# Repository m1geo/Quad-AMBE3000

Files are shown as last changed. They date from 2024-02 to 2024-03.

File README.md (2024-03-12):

# Quad-AMBE3000
A PCB for four DVSI AMBE-3000R (or AMBE-3003) Vocoders for use with WebSDRs/Audio transcoding.

Using four AMBE-3000R parts was cheaper than using a single AMBE-3003, which was the original plan. 
This is useful for VHF, UHF, SHF WebSDR platforms that decode D-Star, DMR, YSF, NXDN, P25, etc.
A soft-codec approach based on [mbelib](https://github.com/szechyjs/mbelib) can be used, but appeared to give poorer decode audio when tested.

Using four AMBE-3003 parts gives a total of 12 similtaneous transcode streams. the '3003 part requires 1V9 instead of 1V8. You may also benefit from increasing the `S_COM_RATE` to 921,600kbps, by changing `S_COM_RATE0` from low to high. See the devices respective datasheets.

The DVSI AMBE parts can be purchased in low volume from the [DVSI Inc. Hardware Product Pricing](https://www.dvsinc.com/products/price.shtml) page. You will need to create a purchase order to buy from DVSI.

# Assembly

The design schematic include details for [JLCPCB](https://jlcpcb.com/) assembly, who assembled mine. You'll likely have to reflow the DVSI AMBE-3000R part yourself, which I did with a PCB reflow hotplate, but you can do any way you wish.

Each schematic component has a [JLCPCB Parts](https://jlcpcb.com/parts)/[LCSC](https://www.lcsc.com/) part number (Cxxxxxx), which can be exported to the BoM using the extra field "LCSC".

# Schematic

[PDF schematic can be found here](outputs/Quad-AMBE3000_Sch.pdf)

# Images

Front PCB

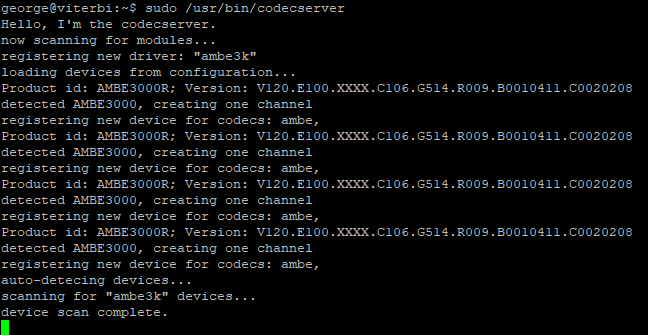
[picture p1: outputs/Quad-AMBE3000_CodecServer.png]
OpenWebRX CodecServer


# 3D Renders

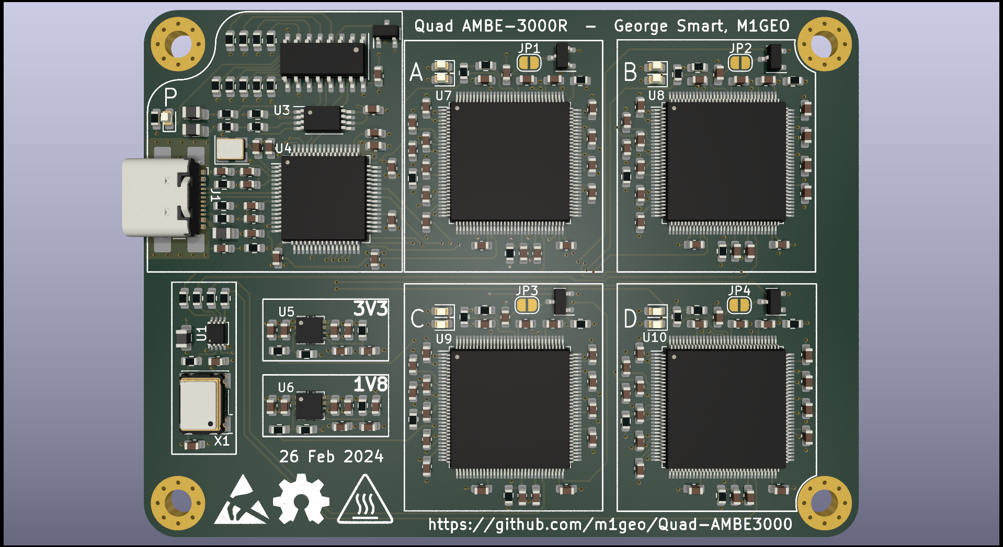
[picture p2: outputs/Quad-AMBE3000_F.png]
Front Render


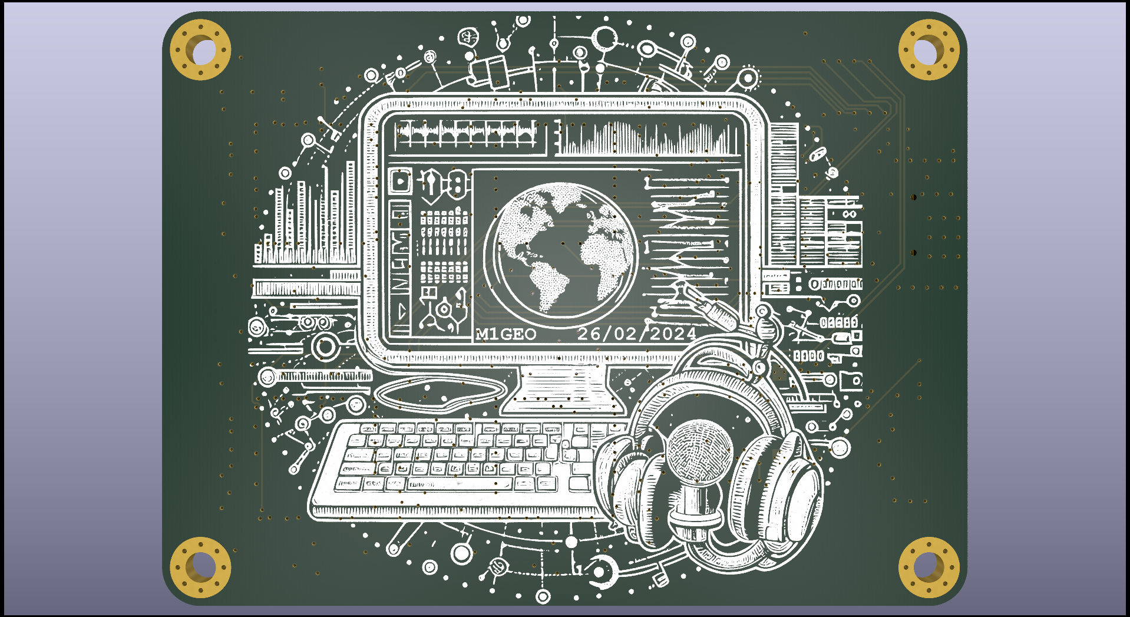
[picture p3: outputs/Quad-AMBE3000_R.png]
Rear Render


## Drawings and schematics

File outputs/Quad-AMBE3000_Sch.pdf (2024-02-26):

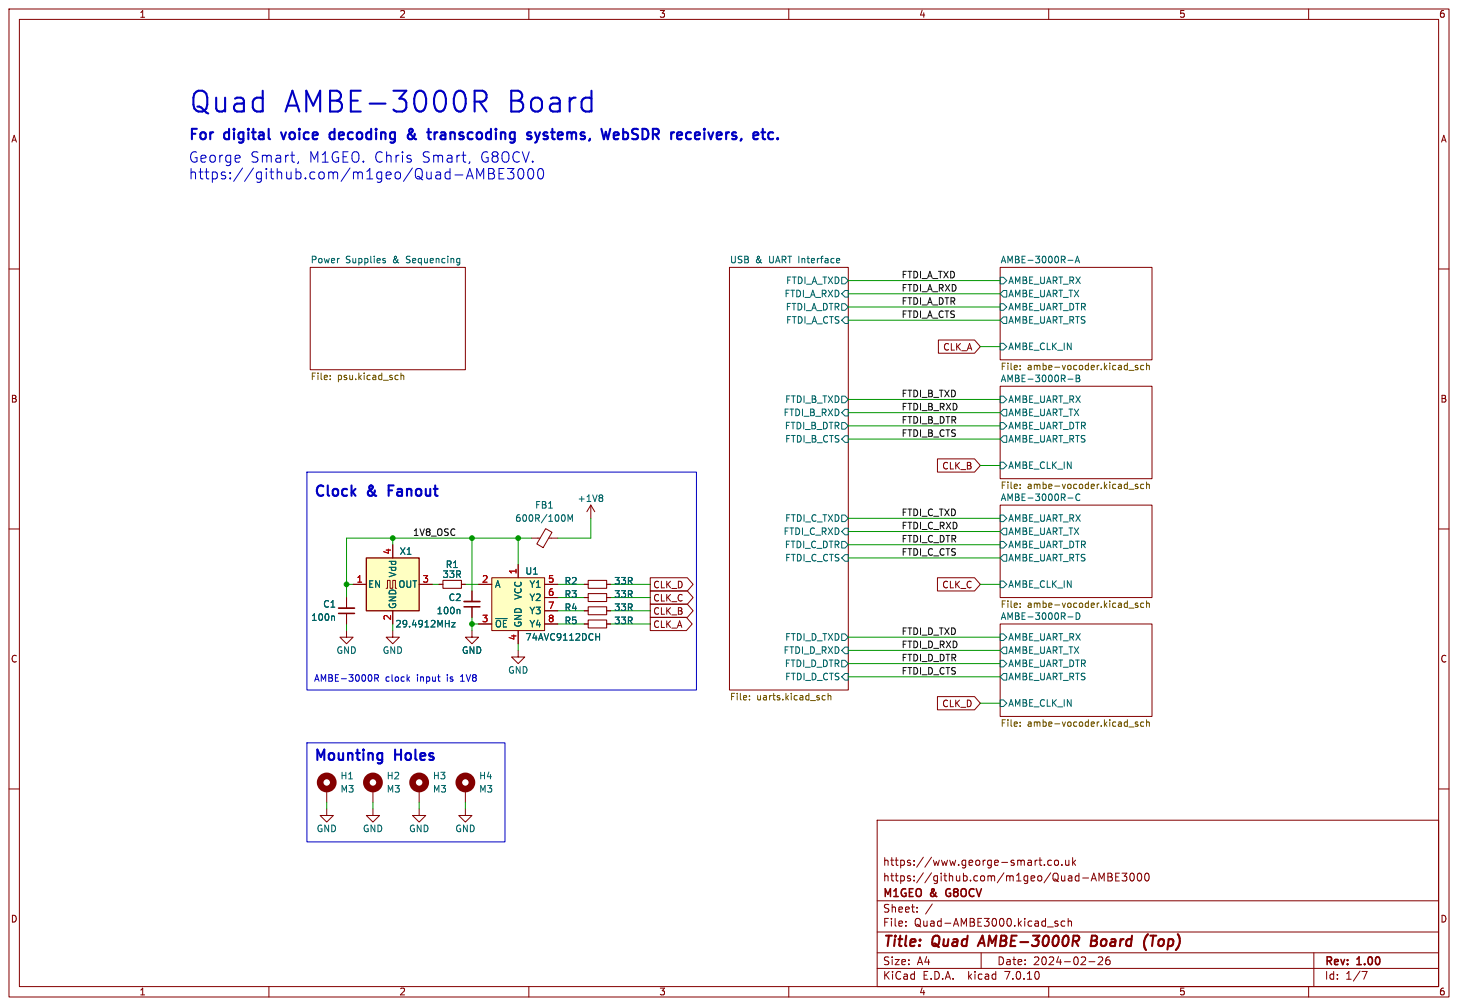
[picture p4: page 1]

For digital voice decoding & transcoding systems, WebSDR receivers, etc.
https://github.com/m1geo/Quad-AMBE3000

https://www.george-smart.co.uk

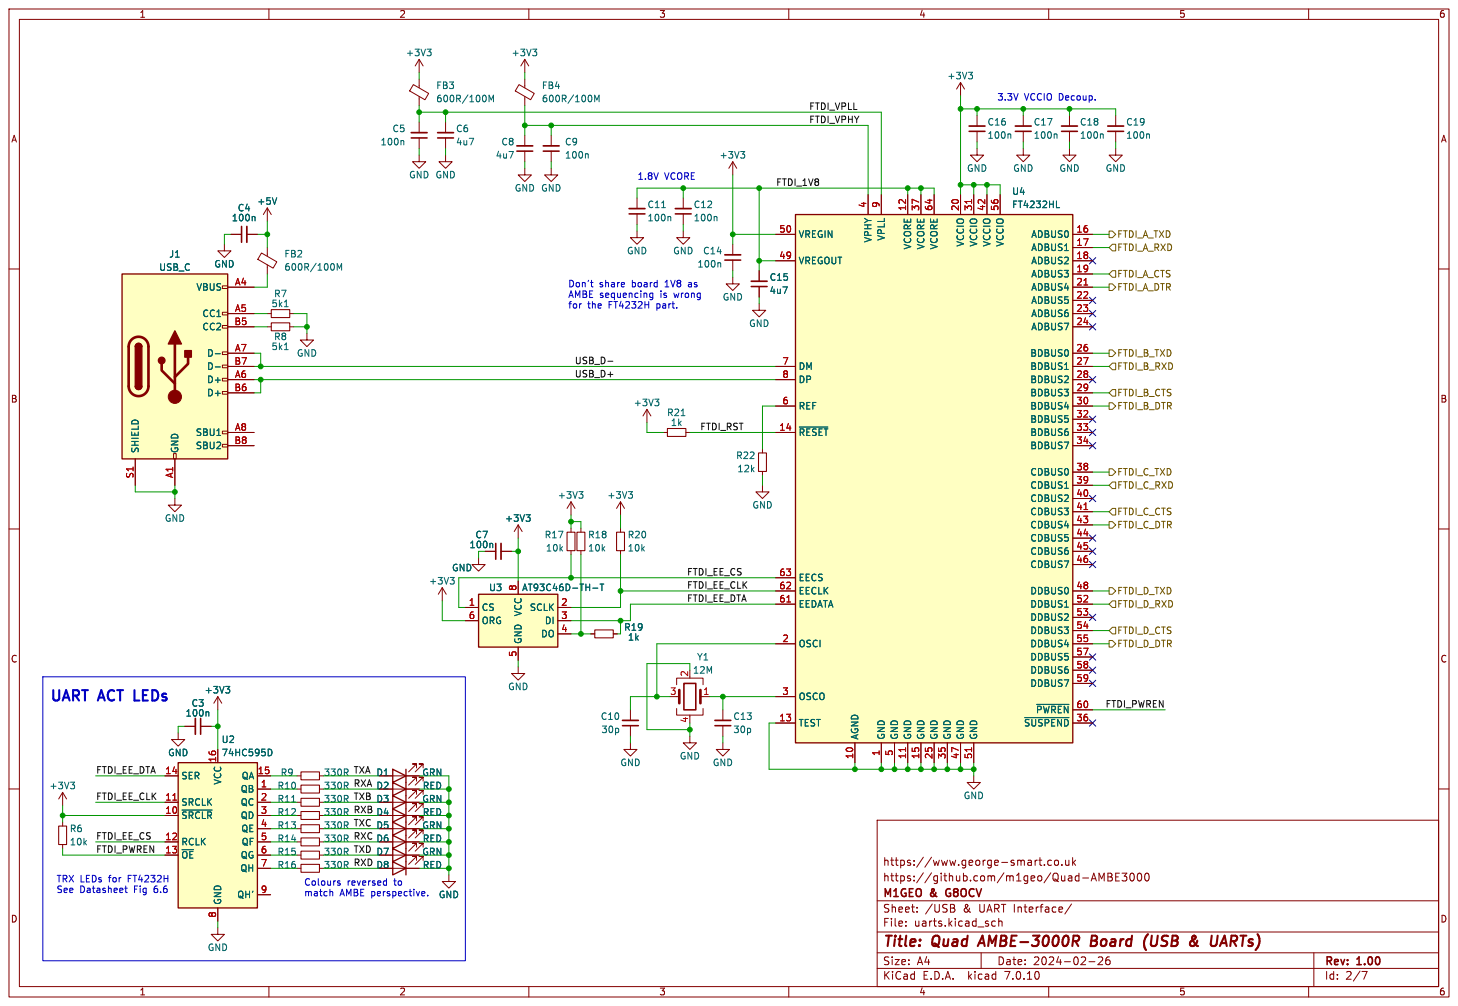
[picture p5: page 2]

1 AGND 10 GND 11 VCORE 12 TEST 13 ~{RESET} 14 GND 15 ADBUS0 16 ADBUS1 17 ADBUS2 18 ADBUS3 19 OSCI 2 VCCIO 20 ADBUS4 21 ADBUS5 22 ADBUS6 23 ADBUS7 24 GND 25 BDBUS0 26 BDBUS1 27 BDBUS2 28 BDBUS3 29 OSCO 3 BDBUS4 30 VCCIO 31 BDBUS5 32 BDBUS6 33 BDBUS7 34 GND 35

4 CDBUS2 40 CDBUS3 41 VCCIO 42 CDBUS4 43 CDBUS5 44 CDBUS6 45 CDBUS7 46 GND 47 DDBUS0 48 VREGOUT 49 GND

5 VREGIN 50 GND 51 DDBUS1 52 DDBUS2 53 DDBUS3 54 DDBUS4 55 VCCIO 56 DDBUS5 57 DDBUS6 58 DDBUS7 59 REF 6 ~{PWREN}60 EEDATA 61 EECLK 62 EECS 63 VCORE 64 DM 7 DP 8 VPLL

for the FT4232H part. TRX LEDs for FT4232H

Colours reversed to match AMBE perspective.

https://www.george-smart.co.uk
https://github.com/m1geo/Quad-AMBE3000

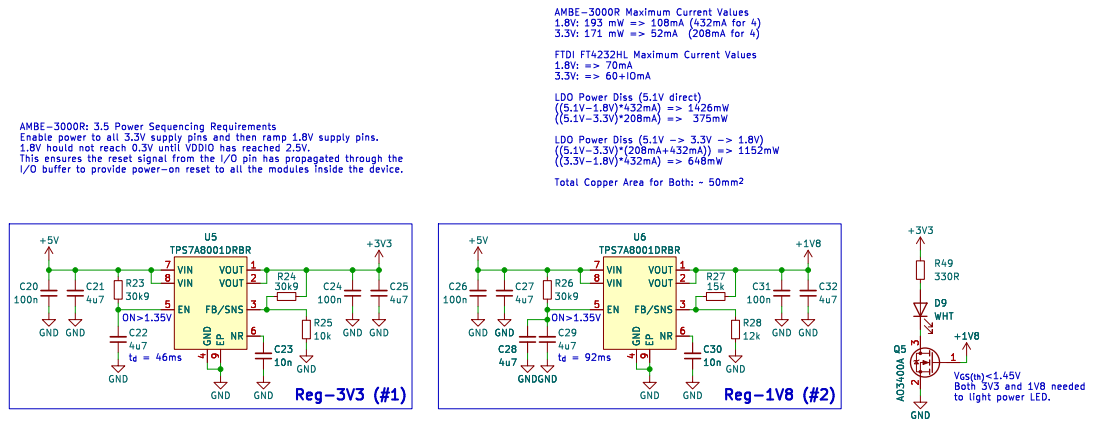
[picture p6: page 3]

LDO Power Diss (5.1V direct)

Total Copper Area for Both: ~ 50mm^{2}

4 EN 5 NR 6 VIN 7 VIN 8 EP

Both 3V3 and 1V8 needed
to light power LED.

https://www.george-smart.co.uk
https://github.com/m1geo/Quad-AMBE3000

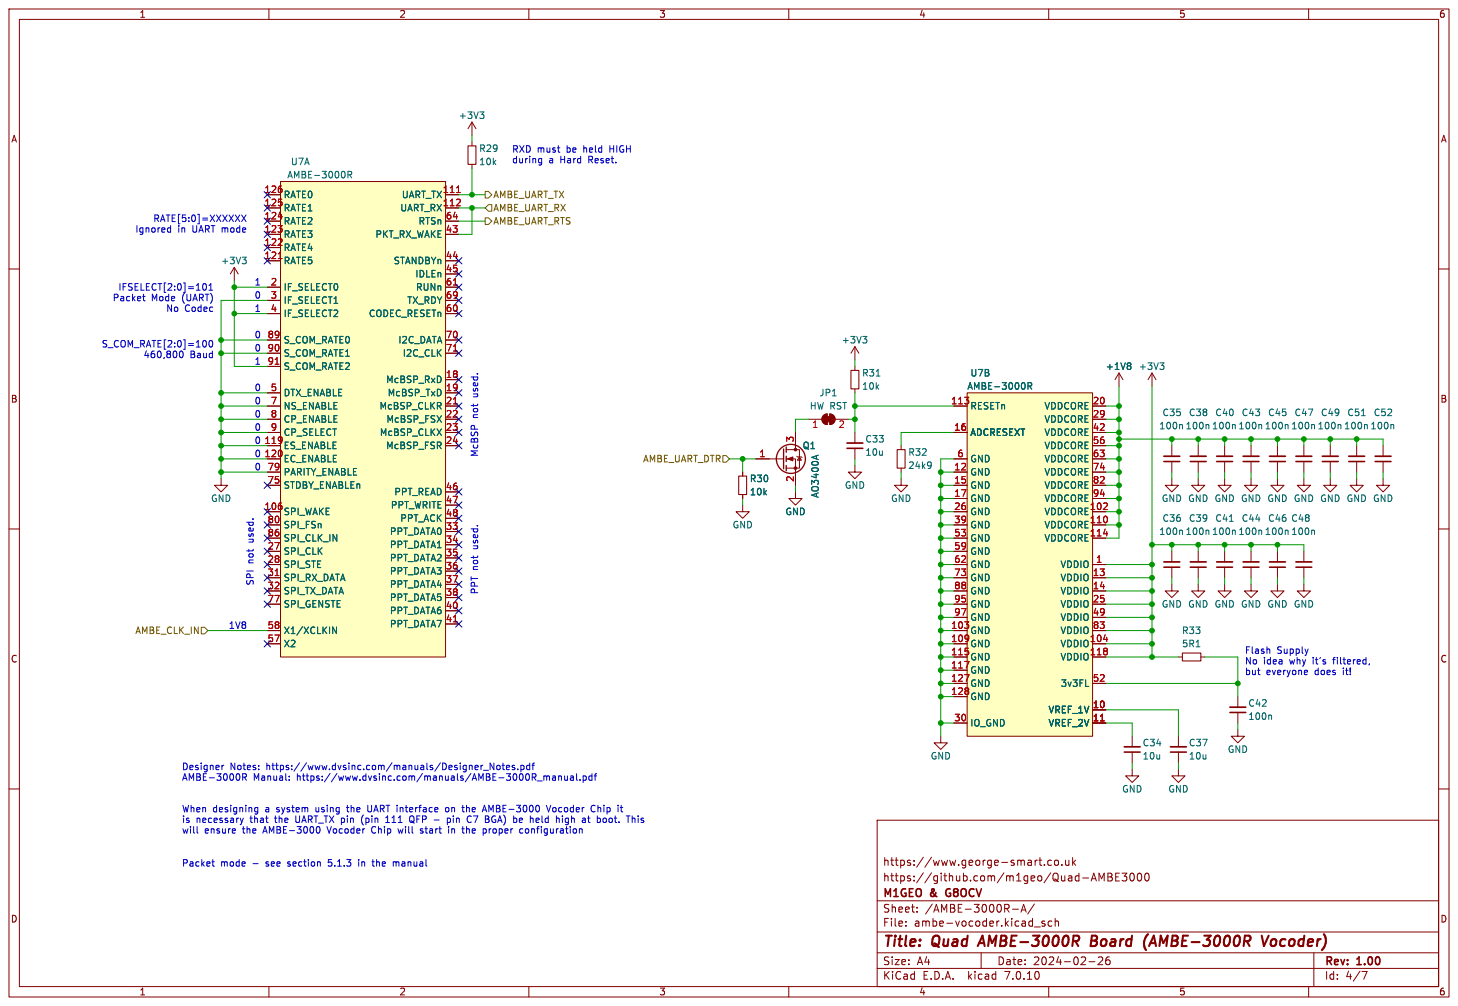
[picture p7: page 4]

0 RATE[5:0]=XXXXXX
Ignored in UART mode

IFSELECT[2:0]=101 Packet Mode (UART) No Codec S_COM_RATE[2:0]=100

Flash Supply No idea why it's filtered, but everyone does it! 0

https://www.george-smart.co.uk
https://github.com/m1geo/Quad-AMBE3000

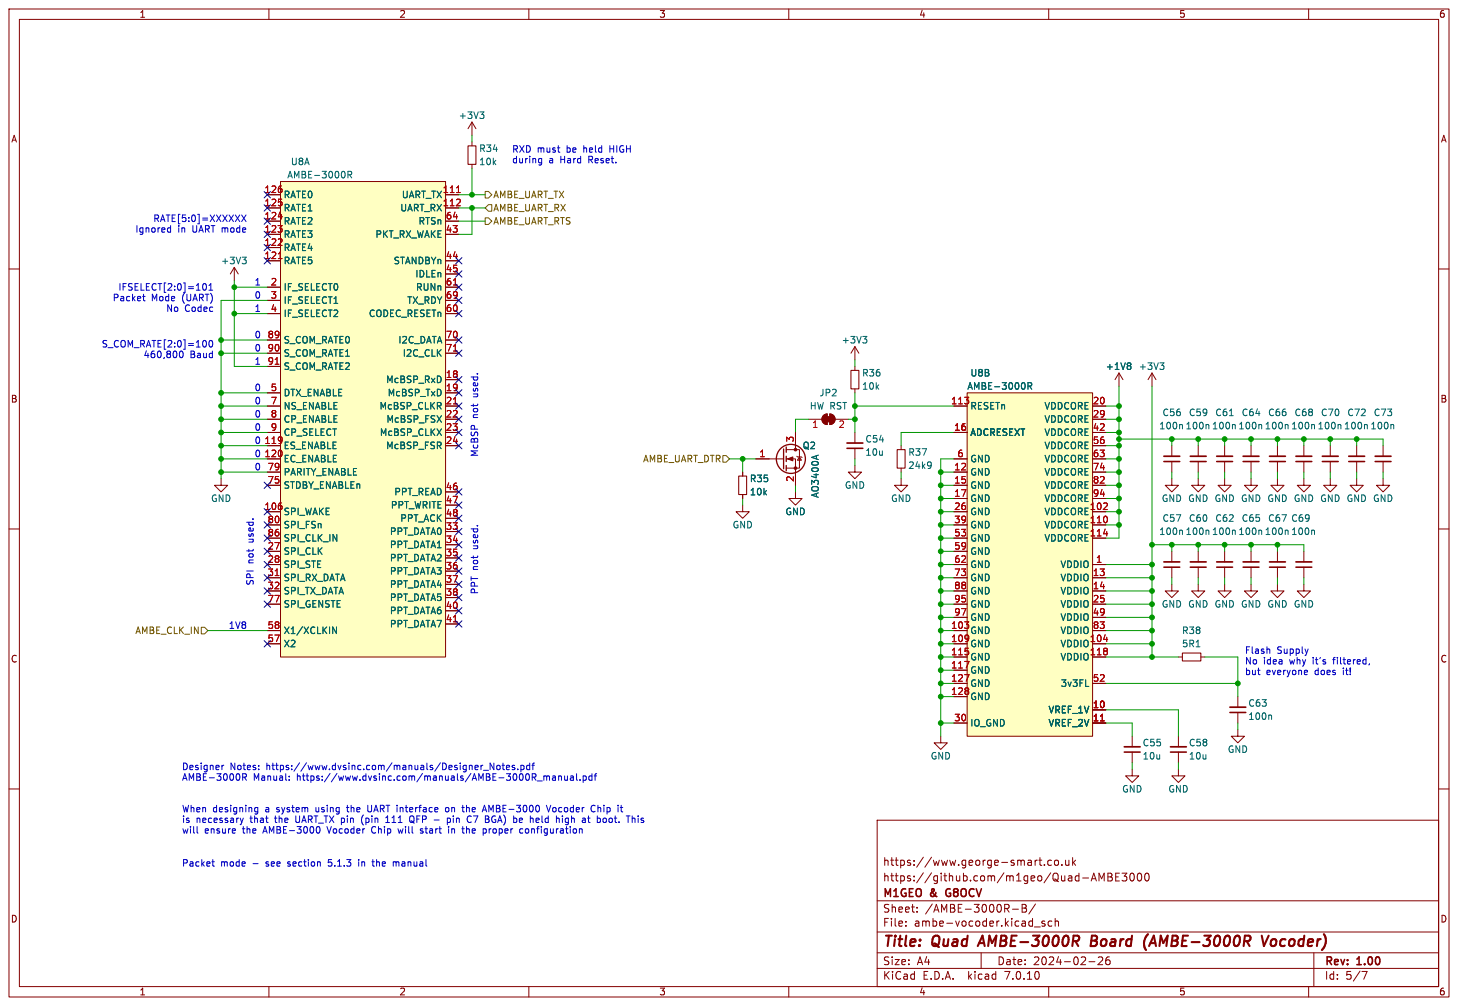
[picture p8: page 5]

0 RATE[5:0]=XXXXXX
Ignored in UART mode

IFSELECT[2:0]=101 Packet Mode (UART) No Codec S_COM_RATE[2:0]=100

Flash Supply No idea why it's filtered, but everyone does it! 0

https://www.george-smart.co.uk
https://github.com/m1geo/Quad-AMBE3000

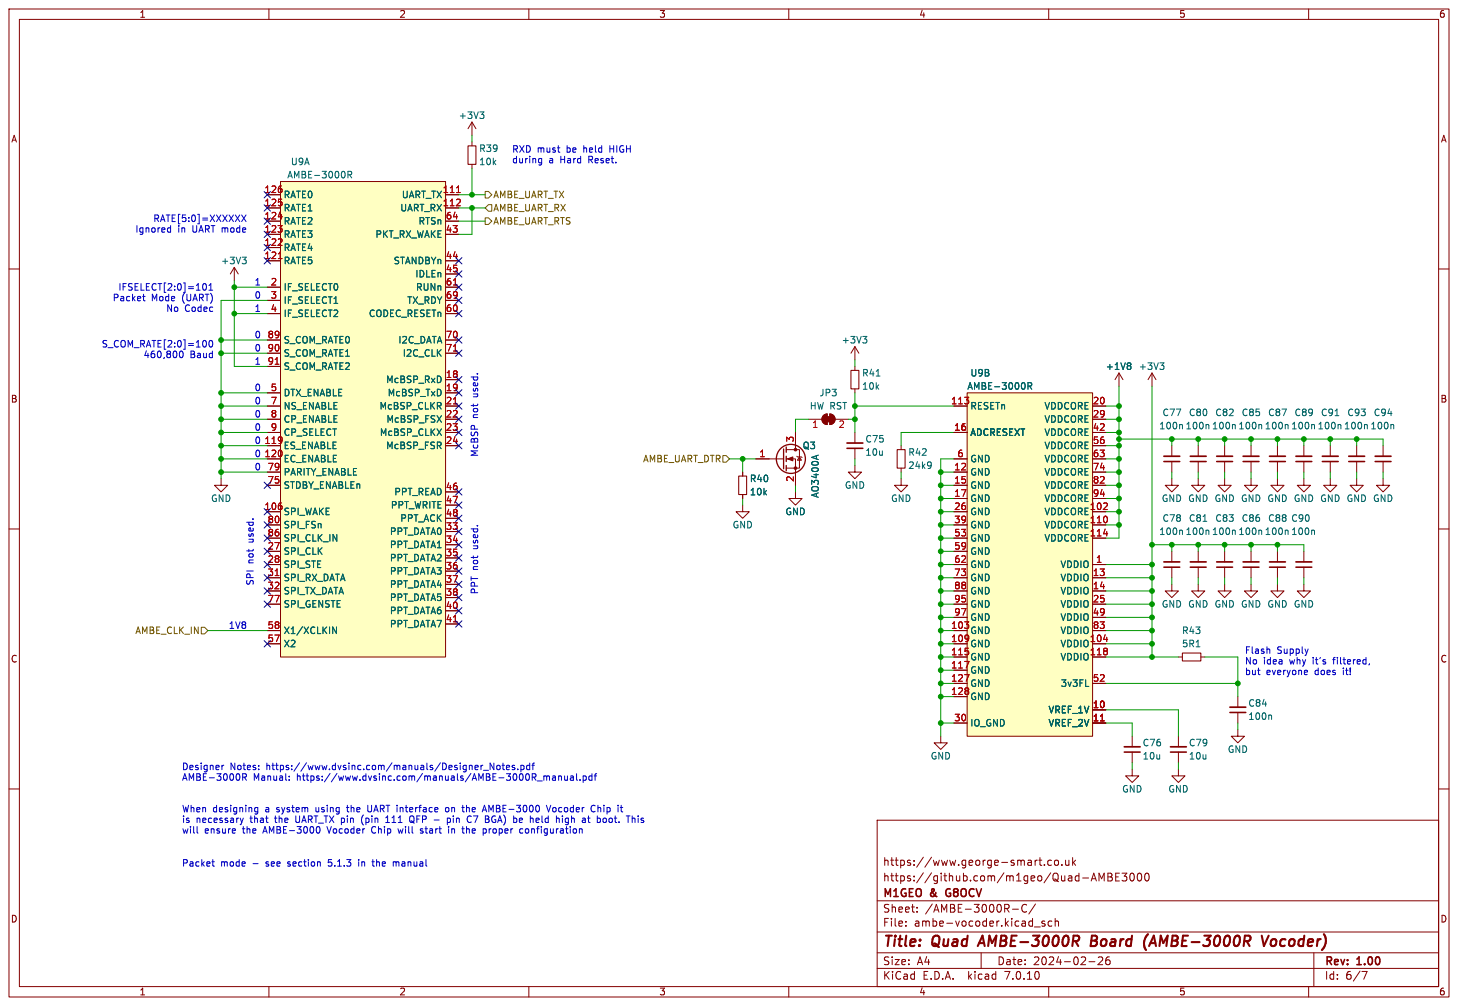
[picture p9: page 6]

0 RATE[5:0]=XXXXXX
Ignored in UART mode

IFSELECT[2:0]=101 Packet Mode (UART) No Codec S_COM_RATE[2:0]=100

Flash Supply No idea why it's filtered, but everyone does it! 0

https://www.george-smart.co.uk
https://github.com/m1geo/Quad-AMBE3000

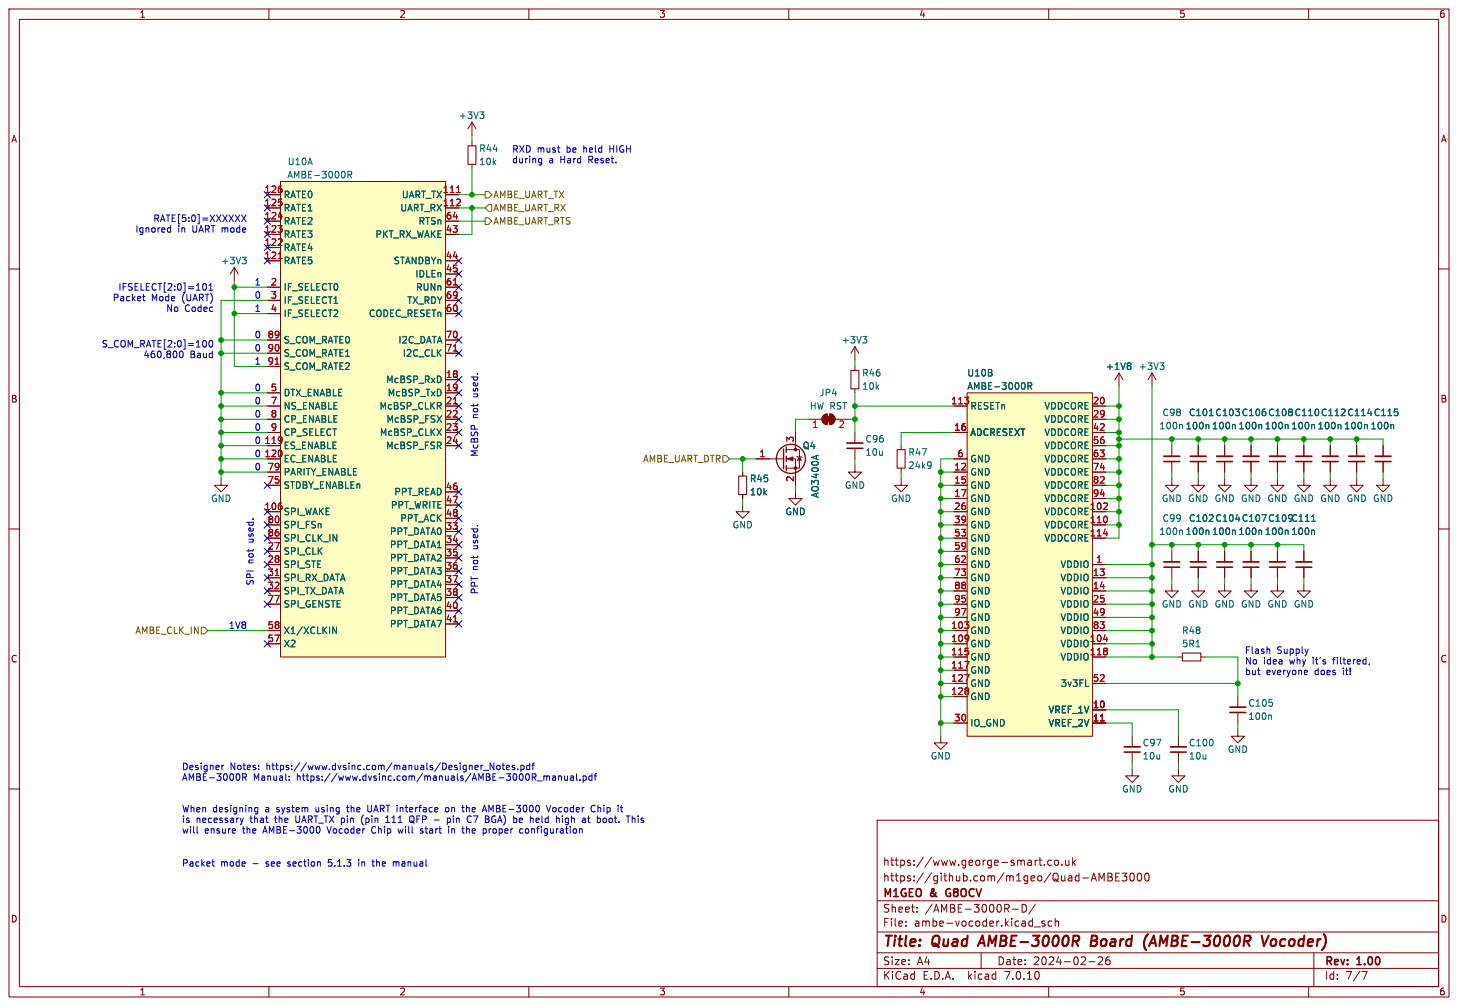
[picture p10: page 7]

0 RATE[5:0]=XXXXXX
Ignored in UART mode

IFSELECT[2:0]=101 Packet Mode (UART) No Codec S_COM_RATE[2:0]=100

Flash Supply No idea why it's filtered, but everyone does it! 0

https://www.george-smart.co.uk
https://github.com/m1geo/Quad-AMBE3000

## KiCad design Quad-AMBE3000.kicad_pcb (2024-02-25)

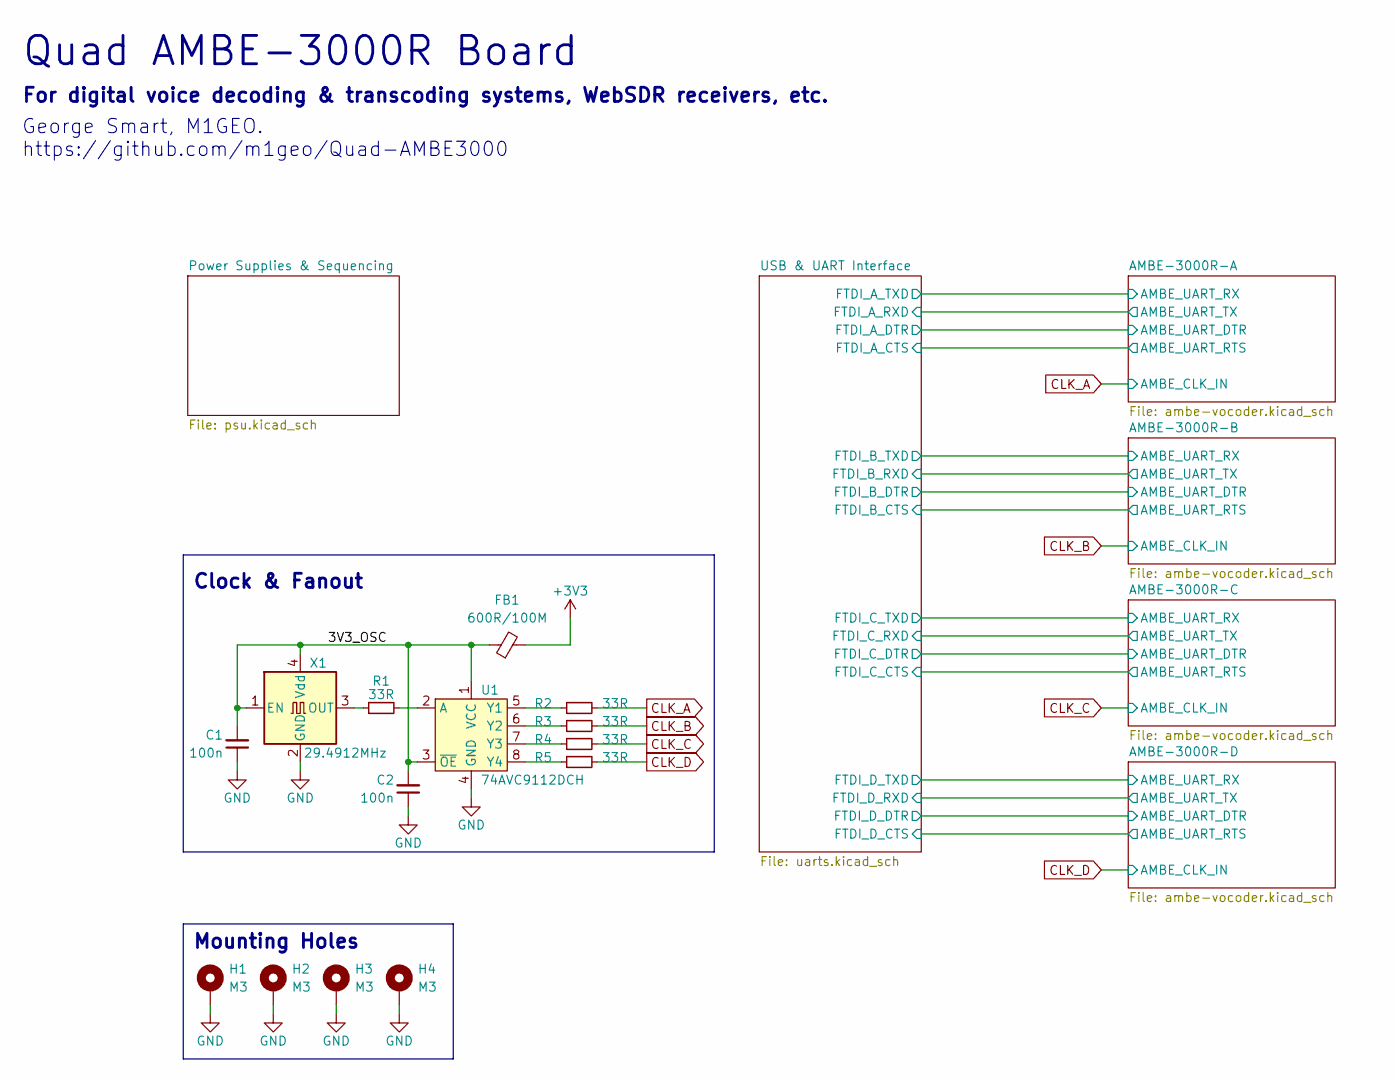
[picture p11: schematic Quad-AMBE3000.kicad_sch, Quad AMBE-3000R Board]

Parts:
C1, C2: 100n; C_0603_1608Metric
FB1: 600R/100M; L_0805_2012Metric; LCSC C1017
H1, H2, H3, H4: M3; MountingHole_3.2mm_M3_Pad_Via
R1, R2, R3, R4, R5: 33R; R_0603_1608Metric
U1: 74AVC9112DCH; VSSOP-8_2.4x2.1mm_P0.5mm; LCSC C546283
X1: 29.4912MHz; Oscillator_SMD_Abracon_ASV-4Pin_7.0x5.1mm; LCSC C2901492

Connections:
+3V3: FB1.2; also elsewhere on the board
/3V3_OSC: C1.2, C2.2, FB1.1, U1.1 (VCC), U1.3 (~OE), X1.1 (EN), X1.4 (Vdd)
CLK_A: R2.2; also elsewhere on the board
CLK_B: R3.2; also elsewhere on the board
CLK_C: R4.2; also elsewhere on the board
CLK_D: R5.2; also elsewhere on the board
GND: C1.1, C2.1, H1.1, H2.1, H3.1, H4.1, U1.4 (GND), X1.2 (GND); also elsewhere on the board
unnamed: R1.2, U1.2 (A)
unnamed: R2.1, U1.5 (Y1)
unnamed: R3.1, U1.6 (Y2)
unnamed: R4.1, U1.7 (Y3)
unnamed: R5.1, U1.8 (Y4)
unnamed: R1.1, X1.3 (OUT)

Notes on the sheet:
George Smart, M1GEO. https://github.com/m1geo/Quad-AMBE3000
Quad AMBE-3000R Board
For digital voice decoding & transcoding systems, WebSDR receivers, etc.
Clock & Fanout
Mounting Holes

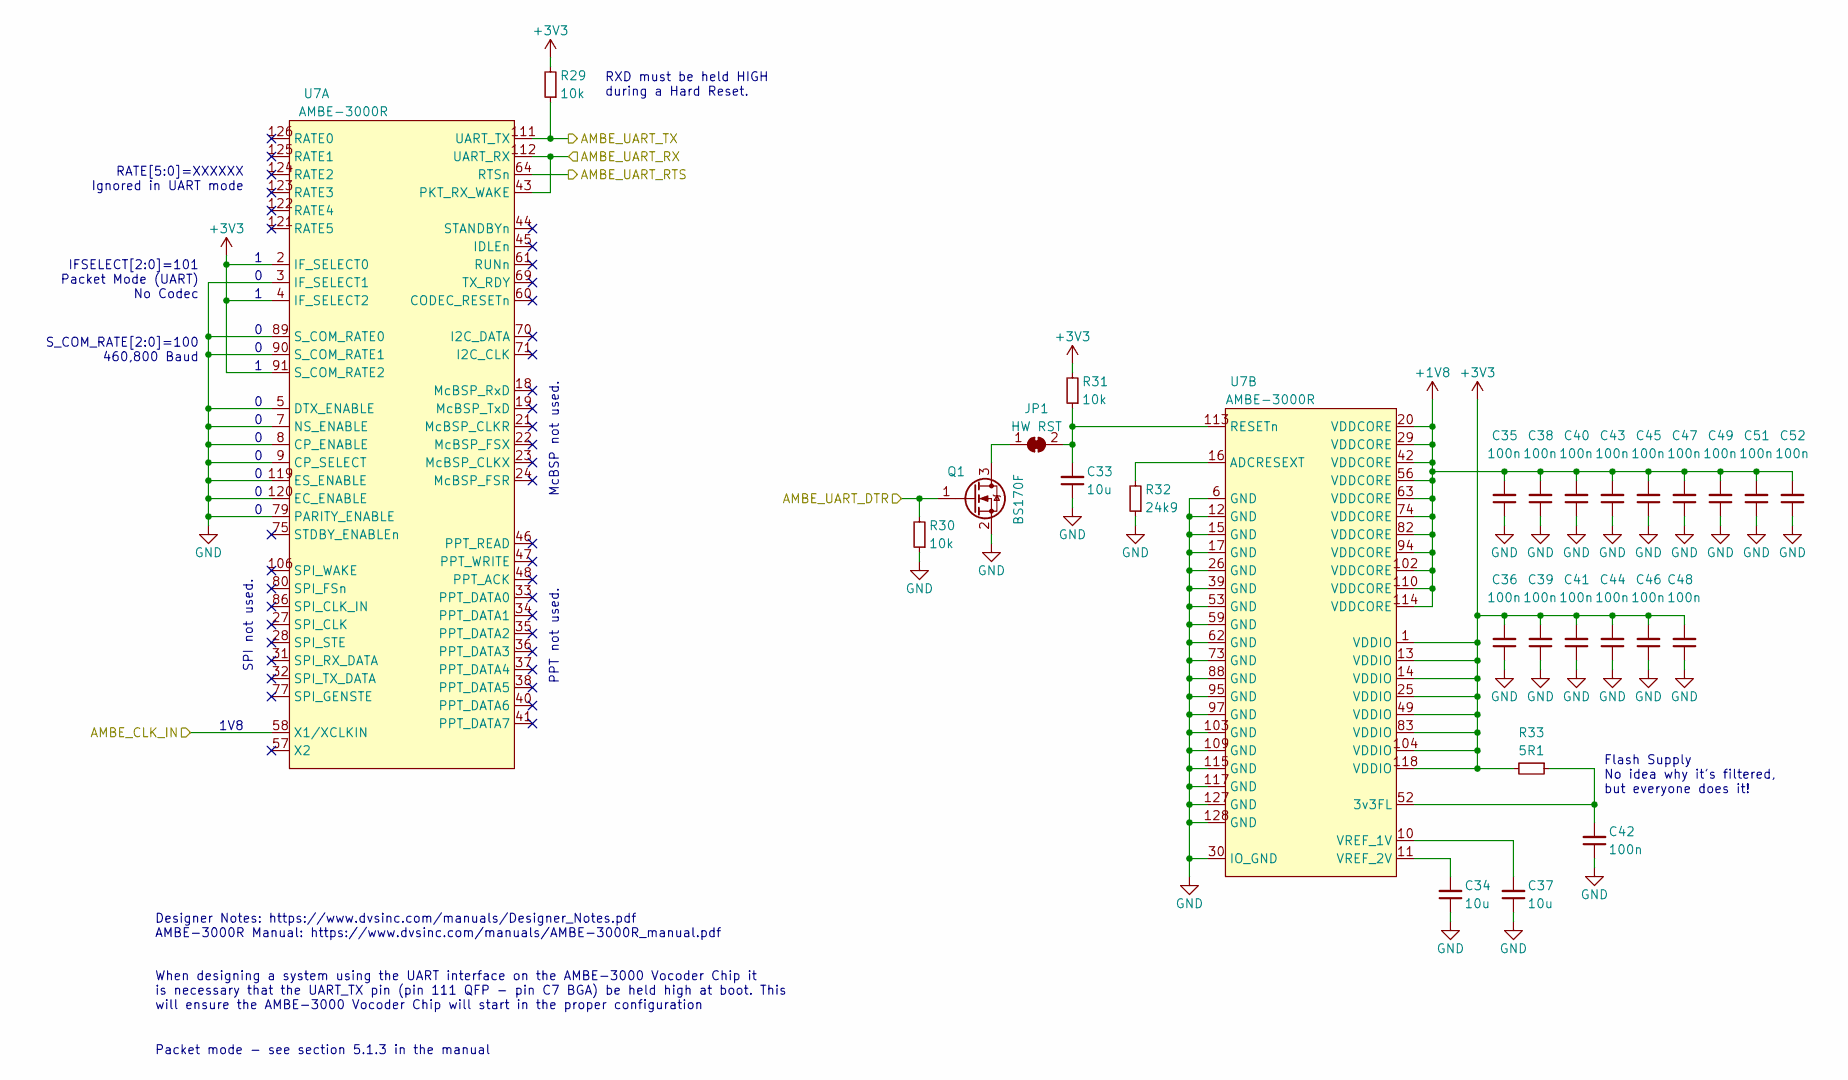
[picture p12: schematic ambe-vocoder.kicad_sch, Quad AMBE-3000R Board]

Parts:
C33, C34, C37: 10u; C_0603_1608Metric
C35, C36, C38, C39, C40, C41, C42, C43, C44, C45, C46, C47, C48, C49, C51, C52: 100n; C_0603_1608Metric
JP1: HW RST; SolderJumper-2_P1.3mm_Bridged_RoundedPad1.0x1.5mm
Q1: BS170F; SOT-23
R29, R30, R31: 10k; R_0603_1608Metric
R32: 24k9; R_0603_1608Metric
R33: 5R1; R_0603_1608Metric
U7: AMBE-3000R; LQFP-128_14x14mm_P0.4mm; LCSC DNF

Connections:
+1V8: C35.2, C38.2, C40.2, C43.2, C45.2, C47.2, C49.2, C51.2, C52.2, U7.20 (VDDCORE), U7.29 (VDDCORE), U7.42 (VDDCORE), U7.56 (VDDCORE), U7.63 (VDDCORE), U7.74 (VDDCORE), U7.82 (VDDCORE), U7.94 (VDDCORE), U7.102 (VDDCORE), U7.110 (VDDCORE), U7.114 (VDDCORE); also elsewhere on the board
+3V3: C36.2, C39.2, C41.2, C44.2, C46.2, C48.2, R29.2, R31.2, R33.2, U7.1 (VDDIO), U7.2 (IF_SELECT0), U7.4 (IF_SELECT2), U7.13 (VDDIO), U7.14 (VDDIO), U7.25 (VDDIO), U7.49 (VDDIO), U7.83 (VDDIO), U7.91 (S_COM_RATE2), U7.104 (VDDIO), U7.118 (VDDIO); also elsewhere on the board
/AMBE-3000R-A/AMBE_UART_DTR: Q1.1 (G), R30.2; also elsewhere on the board
/AMBE-3000R-A/AMBE_UART_RTS: U7.64 (RTSn); also elsewhere on the board
/AMBE-3000R-A/AMBE_UART_RX: U7.43 (PKT_RX_WAKE), U7.112 (UART_RX); also elsewhere on the board
/AMBE-3000R-A/AMBE_UART_TX: R29.1, U7.111 (UART_TX); also elsewhere on the board
CLK_A: U7.58 (X1/XCLKIN); also elsewhere on the board
GND: C33.1, C34.1, C35.1, C36.1, C37.1, C38.1, C39.1, C40.1, C41.1, C42.1, C43.1, C44.1, C45.1, C46.1, C47.1, C48.1, C49.1, C51.1, C52.1, Q1.2 (S), R30.1, R32.1, U7.3 (IF_SELECT1), U7.5 (DTX_ENABLE), U7.6 (GND), U7.7 (NS_ENABLE), U7.8 (CP_ENABLE), U7.9 (CP_SELECT), U7.12 (GND), U7.15 (GND), U7.17 (GND), U7.26 (GND), U7.30 (IO_GND), U7.39 (GND), U7.53 (GND), U7.59 (GND), U7.62 (GND), U7.73 (GND), U7.79 (PARITY_ENABLE), U7.88 (GND), U7.89 (S_COM_RATE0), U7.90 (S_COM_RATE1), U7.95 (GND), U7.97 (GND), U7.103 (GND), U7.109 (GND), U7.115 (GND), U7.117 (GND), U7.119 (ES_ENABLE), U7.120 (EC_ENABLE), U7.127 (GND), U7.128 (GND); also elsewhere on the board
unnamed: JP1.1 (A), Q1.3 (D)
unnamed: C33.2, JP1.2 (B), R31.1, U7.113 (RESETn)
unnamed: C42.2, R33.1, U7.52 (3v3FL)
unnamed: R32.2, U7.16 (ADCRESEXT)
unnamed: C37.2, U7.10 (VREF_1V)
unnamed: C34.2, U7.11 (VREF_2V)

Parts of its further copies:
C54, C55, C58, C75, C76, C79, C96, C97, C100: 10u; C_0603_1608Metric
C56, C57, C59, C60, C61, C62, C63, C64, C65, C66, C67, C68, C69, C70, C72, C73, C77, C78, C80, C81, C82, C83, C84, C85, C86, C87, C88, C89, C90, C91, C93, C94, C98, C99, C101, C102, C103, C104, C105, C106, C107, C108, C109, C110, C111, C112, C114, C115: 100n; C_0603_1608Metric
JP2, JP3, JP4: HW RST; SolderJumper-2_P1.3mm_Bridged_RoundedPad1.0x1.5mm
Q2, Q3, Q4: BS170F; SOT-23
R34, R35, R36, R39, R40, R41, R44, R45, R46: 10k; R_0603_1608Metric
R37, R42, R47: 24k9; R_0603_1608Metric
R38, R43, R48: 5R1; R_0603_1608Metric
U8, U9, U10: AMBE-3000R; LQFP-128_14x14mm_P0.4mm; LCSC DNF

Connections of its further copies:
+1V8: C56.2, C59.2, C61.2, C64.2, C66.2, C68.2, C70.2, C72.2, C73.2, C77.2, C80.2, C82.2, C85.2, C87.2, C89.2, C91.2, C93.2, C94.2, C98.2, C101.2, C103.2, C106.2, C108.2, C110.2, C112.2, C114.2, C115.2, U8.20 (VDDCORE), U8.29 (VDDCORE), U8.42 (VDDCORE), U8.56 (VDDCORE), U8.63 (VDDCORE), U8.74 (VDDCORE), U8.82 (VDDCORE), U8.94 (VDDCORE), U8.102 (VDDCORE), U8.110 (VDDCORE), U8.114 (VDDCORE), U9.20 (VDDCORE), U9.29 (VDDCORE), U9.42 (VDDCORE), U9.56 (VDDCORE), U9.63 (VDDCORE), U9.74 (VDDCORE), U9.82 (VDDCORE), U9.94 (VDDCORE), U9.102 (VDDCORE), U9.110 (VDDCORE), U9.114 (VDDCORE), U10.20 (VDDCORE), U10.29 (VDDCORE), U10.42 (VDDCORE), U10.56 (VDDCORE), U10.63 (VDDCORE), U10.74 (VDDCORE), U10.82 (VDDCORE), U10.94 (VDDCORE), U10.102 (VDDCORE), U10.110 (VDDCORE), U10.114 (VDDCORE); also elsewhere on the board
+3V3: C57.2, C60.2, C62.2, C65.2, C67.2, C69.2, C78.2, C81.2, C83.2, C86.2, C88.2, C90.2, C99.2, C102.2, C104.2, C107.2, C109.2, C111.2, R34.2, R36.2, R38.2, R39.2, R41.2, R43.2, R44.2, R46.2, R48.2, U8.1 (VDDIO), U8.2 (IF_SELECT0), U8.4 (IF_SELECT2), U8.13 (VDDIO), U8.14 (VDDIO), U8.25 (VDDIO), U8.49 (VDDIO), U8.83 (VDDIO), U8.91 (S_COM_RATE2), U8.104 (VDDIO), U8.118 (VDDIO), U9.1 (VDDIO), U9.2 (IF_SELECT0), U9.4 (IF_SELECT2), U9.13 (VDDIO), U9.14 (VDDIO), U9.25 (VDDIO), U9.49 (VDDIO), U9.83 (VDDIO), U9.91 (S_COM_RATE2), U9.104 (VDDIO), U9.118 (VDDIO), U10.1 (VDDIO), U10.2 (IF_SELECT0), U10.4 (IF_SELECT2), U10.13 (VDDIO), U10.14 (VDDIO), U10.25 (VDDIO), U10.49 (VDDIO), U10.83 (VDDIO), U10.91 (S_COM_RATE2), U10.104 (VDDIO), U10.118 (VDDIO); also elsewhere on the board
/AMBE-3000R-B/AMBE_UART_DTR: Q2.1 (G), R35.2; also elsewhere on the board
/AMBE-3000R-B/AMBE_UART_RTS: U8.64 (RTSn); also elsewhere on the board
/AMBE-3000R-B/AMBE_UART_RX: U8.43 (PKT_RX_WAKE), U8.112 (UART_RX); also elsewhere on the board
/AMBE-3000R-B/AMBE_UART_TX: R34.1, U8.111 (UART_TX); also elsewhere on the board
/AMBE-3000R-C/AMBE_UART_DTR: Q3.1 (G), R40.2; also elsewhere on the board
/AMBE-3000R-C/AMBE_UART_RTS: U9.64 (RTSn); also elsewhere on the board
/AMBE-3000R-C/AMBE_UART_RX: U9.43 (PKT_RX_WAKE), U9.112 (UART_RX); also elsewhere on the board
/AMBE-3000R-C/AMBE_UART_TX: R39.1, U9.111 (UART_TX); also elsewhere on the board
/AMBE-3000R-D/AMBE_UART_DTR: Q4.1 (G), R45.2; also elsewhere on the board
/AMBE-3000R-D/AMBE_UART_RTS: U10.64 (RTSn); also elsewhere on the board
/AMBE-3000R-D/AMBE_UART_RX: U10.43 (PKT_RX_WAKE), U10.112 (UART_RX); also elsewhere on the board
/AMBE-3000R-D/AMBE_UART_TX: R44.1, U10.111 (UART_TX); also elsewhere on the board
CLK_B: U8.58 (X1/XCLKIN); also elsewhere on the board
CLK_C: U9.58 (X1/XCLKIN); also elsewhere on the board
CLK_D: U10.58 (X1/XCLKIN); also elsewhere on the board
GND: C54.1, C55.1, C56.1, C57.1, C58.1, C59.1, C60.1, C61.1, C62.1, C63.1, C64.1, C65.1, C66.1, C67.1, C68.1, C69.1, C70.1, C72.1, C73.1, C75.1, C76.1, C77.1, C78.1, C79.1, C80.1, C81.1, C82.1, C83.1, C84.1, C85.1, C86.1, C87.1, C88.1, C89.1, C90.1, C91.1, C93.1, C94.1, C96.1, C97.1, C98.1, C99.1, C100.1, C101.1, C102.1, C103.1, C104.1, C105.1, C106.1, C107.1, C108.1, C109.1, C110.1, C111.1, C112.1, C114.1, C115.1, Q2.2 (S), Q3.2 (S), Q4.2 (S), R35.1, R37.1, R40.1, R42.1, R45.1, R47.1, U8.3 (IF_SELECT1), U8.5 (DTX_ENABLE), U8.6 (GND), U8.7 (NS_ENABLE), U8.8 (CP_ENABLE), U8.9 (CP_SELECT), U8.12 (GND), U8.15 (GND), U8.17 (GND), U8.26 (GND), U8.30 (IO_GND), U8.39 (GND), U8.53 (GND), U8.59 (GND), U8.62 (GND), U8.73 (GND), U8.79 (PARITY_ENABLE), U8.88 (GND), U8.89 (S_COM_RATE0), U8.90 (S_COM_RATE1), U8.95 (GND), U8.97 (GND), U8.103 (GND), U8.109 (GND), U8.115 (GND), U8.117 (GND), U8.119 (ES_ENABLE), U8.120 (EC_ENABLE), U8.127 (GND), U8.128 (GND), U9.3 (IF_SELECT1), U9.5 (DTX_ENABLE), U9.6 (GND), U9.7 (NS_ENABLE), U9.8 (CP_ENABLE), U9.9 (CP_SELECT), U9.12 (GND), U9.15 (GND), U9.17 (GND), U9.26 (GND), U9.30 (IO_GND), U9.39 (GND), U9.53 (GND), U9.59 (GND), U9.62 (GND), U9.73 (GND), U9.79 (PARITY_ENABLE), U9.88 (GND), U9.89 (S_COM_RATE0), U9.90 (S_COM_RATE1), U9.95 (GND), U9.97 (GND), U9.103 (GND), U9.109 (GND), U9.115 (GND), U9.117 (GND), U9.119 (ES_ENABLE), U9.120 (EC_ENABLE), U9.127 (GND), U9.128 (GND), U10.3 (IF_SELECT1), U10.5 (DTX_ENABLE), U10.6 (GND), U10.7 (NS_ENABLE), U10.8 (CP_ENABLE), U10.9 (CP_SELECT), U10.12 (GND), U10.15 (GND), U10.17 (GND), U10.26 (GND), U10.30 (IO_GND), U10.39 (GND), U10.53 (GND), U10.59 (GND), U10.62 (GND), U10.73 (GND), U10.79 (PARITY_ENABLE), U10.88 (GND), U10.89 (S_COM_RATE0), U10.90 (S_COM_RATE1), U10.95 (GND), U10.97 (GND), U10.103 (GND), U10.109 (GND), U10.115 (GND), U10.117 (GND), U10.119 (ES_ENABLE), U10.120 (EC_ENABLE), U10.127 (GND), U10.128 (GND); also elsewhere on the board
unnamed: JP2.1 (A), Q2.3 (D)
unnamed: C54.2, JP2.2 (B), R36.1, U8.113 (RESETn)
unnamed: JP3.1 (A), Q3.3 (D)
unnamed: C75.2, JP3.2 (B), R41.1, U9.113 (RESETn)
unnamed: JP4.1 (A), Q4.3 (D)
unnamed: C96.2, JP4.2 (B), R46.1, U10.113 (RESETn)
unnamed: C63.2, R38.1, U8.52 (3v3FL)
unnamed: R37.2, U8.16 (ADCRESEXT)
unnamed: C58.2, U8.10 (VREF_1V)
unnamed: C55.2, U8.11 (VREF_2V)
unnamed: C84.2, R43.1, U9.52 (3v3FL)
unnamed: R42.2, U9.16 (ADCRESEXT)
unnamed: C79.2, U9.10 (VREF_1V)
unnamed: C76.2, U9.11 (VREF_2V)
unnamed: C105.2, R48.1, U10.52 (3v3FL)
unnamed: R47.2, U10.16 (ADCRESEXT)
unnamed: C100.2, U10.10 (VREF_1V)
unnamed: C97.2, U10.11 (VREF_2V)

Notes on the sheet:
1V8
IFSELECT[2:0]=101 Packet Mode (UART) No Codec
McBSP not used.
RATE[5:0]=XXXXXX Ignored in UART mode
Packet mode - see section 5.1.3 in the manual
Designer Notes: https://www.dvsinc.com/manuals/Designer_Notes.pdf AMBE-3000R Manual: https://www.dvsinc.com/manuals/AMBE-3000R_manual.pdf
S_COM_RATE[2:0]=100 460,800 Baud
PPT not used.
Flash Supply No idea why it's filtered, but everyone does it!
SPI not used.
RXD must be held HIGH during a Hard Reset.
When designing a system using the UART interface on the AMBE-3000 Vocoder Chip it is necessary that the UART_TX pin (pin 111 QFP - pin C7 BGA) be held high at boot. This will ensure the AMBE-3000 Vocoder Chip will start in the proper configuration

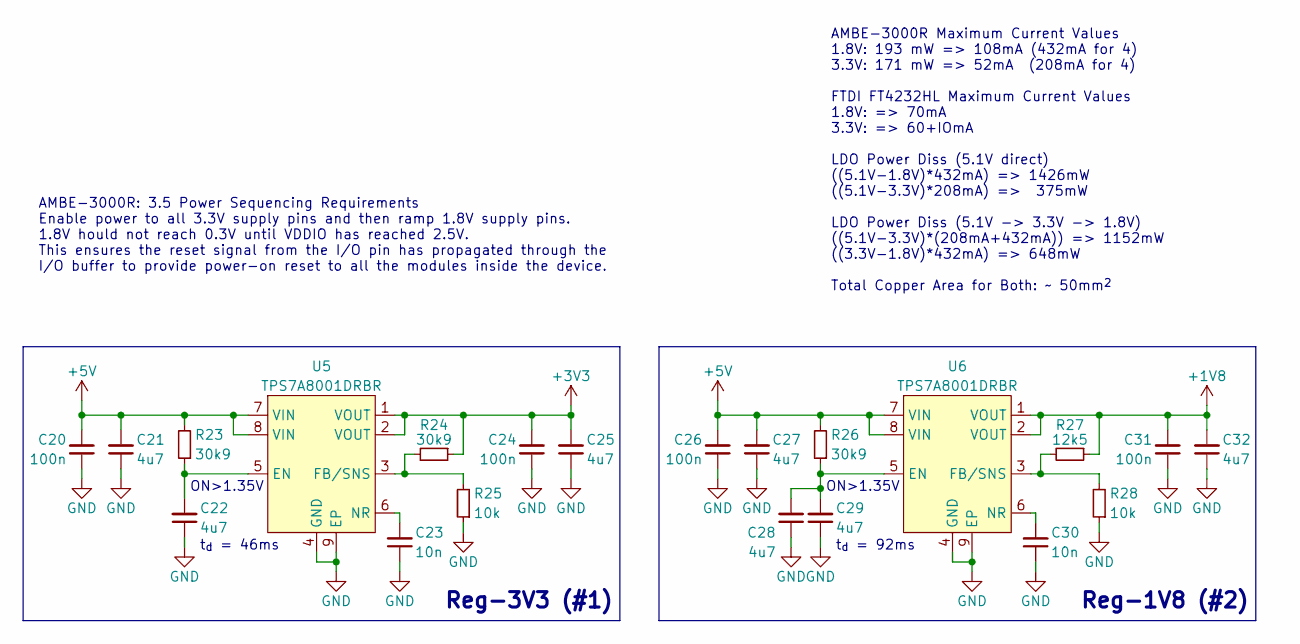
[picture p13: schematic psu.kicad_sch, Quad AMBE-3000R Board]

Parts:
C20, C24, C26, C31: 100n; C_0603_1608Metric
C21, C22, C25, C27, C28, C29, C32: 4u7; C_0603_1608Metric
C23, C30: 10n; C_0603_1608Metric
R23, R24, R26: 30k9; R_0603_1608Metric
R25, R28: 10k; R_0603_1608Metric
R27: 12k5; R_0603_1608Metric
U5, U6: TPS7A8001DRBR; Texas_DRB0008A; LCSC C105265

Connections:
+1V8: C31.2, C32.2, R27.1, U6.1 (VOUT), U6.2 (VOUT); also elsewhere on the board
+3V3: C24.2, C25.2, R24.1, U5.1 (VOUT), U5.2 (VOUT); also elsewhere on the board
+5V: C20.2, C21.2, C26.2, C27.2, R23.2, R26.2, U5.7 (VIN), U5.8 (VIN), U6.7 (VIN), U6.8 (VIN); also elsewhere on the board
GND: C20.1, C21.1, C22.1, C23.1, C24.1, C25.1, C26.1, C27.1, C28.1, C29.1, C30.1, C31.1, C32.1, R25.1, R28.1, U5.4 (GND), U5.9 (EP), U6.4 (GND), U6.9 (EP); also elsewhere on the board
unnamed: C22.2, R23.1, U5.5 (EN)
unnamed: R24.2, R25.2, U5.3 (FB/SNS)
unnamed: C23.2, U5.6 (NR)
unnamed: C28.2, C29.2, R26.1, U6.5 (EN)
unnamed: R27.2, R28.2, U6.3 (FB/SNS)
unnamed: C30.2, U6.6 (NR)

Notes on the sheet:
AMBE-3000R: 3.5 Power Sequencing Requirements Enable power to all 3.3V supply pins and then ramp 1.8V supply pins. 1.8V hould not reach 0.3V until VDDIO has reached 2.5V. This ensures the reset signal from the I/O pin has propagated through the I/O buffer to provide power-on reset to all the module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
AMBE-3000R Maximum Current Values 1.8V: 193 mW => 108mA (432mA for 4) 3.3V: 171 mW => 52mA (208mA for 4) FTDI FT4232HL Maximum Current Values 1.8V: => 70mA 3.3V: => 60+IOmA LDO Power Diss (5.1V direct) ((5.1V-1.8V)*432mA) => 1426mW ((5.1V-3.3V)*208mA) => 375mW LDO Power Diss (5.1V -> 3.3V -> 1.8V) 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
Reg-3V3 (#1)
Reg-1V8 (#2)
t_{d} = 46ms
ON>1.35V
t_{d} = 92ms

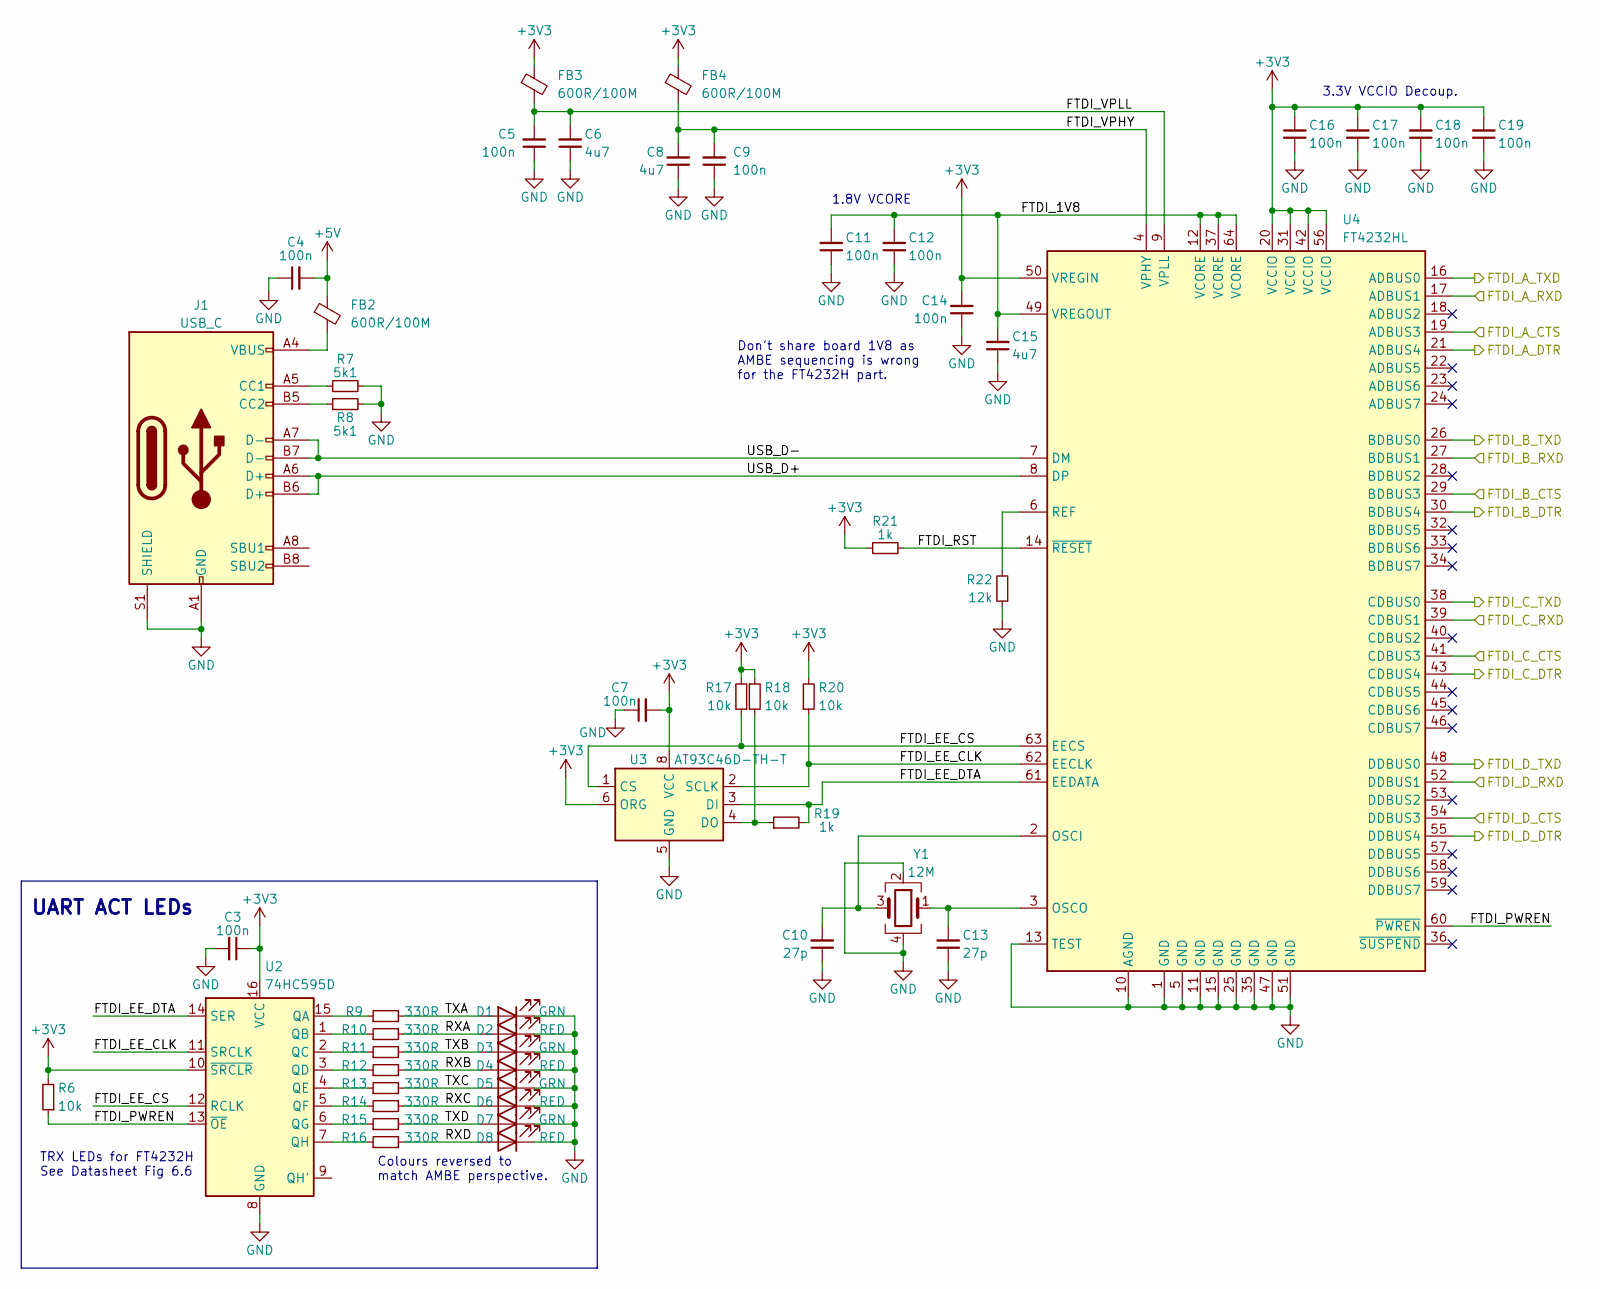
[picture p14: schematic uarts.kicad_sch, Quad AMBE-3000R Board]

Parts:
C3, C4, C5, C7, C9, C11, C12, C14, C16, C17, C18, C19: 100n; C_0603_1608Metric
C6, C8, C15: 4u7; C_0603_1608Metric
C10, C13: 27p; C_0603_1608Metric
D1, D3, D5, D7: GRN; LED_0603_1608Metric
D2, D4, D6, D8: RED; LED_0603_1608Metric
FB2, FB3, FB4: 600R/100M; L_0805_2012Metric; LCSC C1017
J1: USB_C; USB_C_Receptacle_GCT_USB4110; LCSC C963217
R6, R17, R18, R20: 10k; R_0603_1608Metric
R7, R8: 5k1; R_0603_1608Metric
R9, R10, R11, R12, R13, R14, R15, R16: 330R; R_0603_1608Metric
R19, R21: 1k; R_0603_1608Metric
R22: 12k; R_0603_1608Metric
U2: 74HC595D; SO-16_3.9x9.9mm_P1.27mm; LCSC C5947
U3: AT93C46D-TH-T; TSSOP-8_4.4x3mm_P0.65mm; LCSC C2061936
U4: FT4232HL; LQFP-64_10x10mm_P0.5mm; LCSC C56742
Y1: 12M; Crystal_SMD_3225-4Pin_3.2x2.5mm; LCSC C362340

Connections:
+3V3: C3.1, C7.2, C14.2, C16.2, C17.2, C18.2, C19.2, FB3.1, FB4.1, R6.2, R17.2, R18.1, R20.2, R21.1, U2.10 (~SRCLR), U2.16 (VCC), U3.6 (ORG), U3.8 (VCC), U4.20 (VCCIO), U4.31 (VCCIO), U4.42 (VCCIO), U4.50 (VREGIN), U4.56 (VCCIO); also elsewhere on the board
+5V: C4.2, FB2.1; also elsewhere on the board
/AMBE-3000R-A/AMBE_UART_DTR: U4.21 (ADBUS4); also elsewhere on the board
/AMBE-3000R-A/AMBE_UART_RTS: U4.19 (ADBUS3); also elsewhere on the board
/AMBE-3000R-A/AMBE_UART_RX: U4.16 (ADBUS0); also elsewhere on the board
/AMBE-3000R-A/AMBE_UART_TX: U4.17 (ADBUS1); also elsewhere on the board
/AMBE-3000R-B/AMBE_UART_DTR: U4.30 (BDBUS4); also elsewhere on the board
/AMBE-3000R-B/AMBE_UART_RTS: U4.29 (BDBUS3); also elsewhere on the board
/AMBE-3000R-B/AMBE_UART_RX: U4.26 (BDBUS0); also elsewhere on the board
/AMBE-3000R-B/AMBE_UART_TX: U4.27 (BDBUS1); also elsewhere on the board
/AMBE-3000R-C/AMBE_UART_DTR: U4.43 (CDBUS4); also elsewhere on the board
/AMBE-3000R-C/AMBE_UART_RTS: U4.41 (CDBUS3); also elsewhere on the board
/AMBE-3000R-C/AMBE_UART_RX: U4.38 (CDBUS0); also elsewhere on the board
/AMBE-3000R-C/AMBE_UART_TX: U4.39 (CDBUS1); also elsewhere on the board
/AMBE-3000R-D/AMBE_UART_DTR: U4.55 (DDBUS4); also elsewhere on the board
/AMBE-3000R-D/AMBE_UART_RTS: U4.54 (DDBUS3); also elsewhere on the board
/AMBE-3000R-D/AMBE_UART_RX: U4.48 (DDBUS0); also elsewhere on the board
/AMBE-3000R-D/AMBE_UART_TX: U4.52 (DDBUS1); also elsewhere on the board
/USB & UART Interface/FTDI_1V8: C11.2, C12.2, C15.2, U4.12 (VCORE), U4.37 (VCORE), U4.49 (VREGOUT), U4.64 (VCORE)
/USB & UART Interface/FTDI_EE_CLK: R20.1, U2.11 (SRCLK), U3.2 (SCLK), U4.62 (EECLK)
/USB & UART Interface/FTDI_EE_CS: R17.1, U2.12 (RCLK), U3.1 (CS), U4.63 (EECS)
/USB & UART Interface/FTDI_EE_DTA: R19.2, U2.14 (SER), U3.3 (DI), U4.61 (EEDATA)
/USB & UART Interface/FTDI_PWREN: R6.1, U2.13 (~OE), U4.60 (~PWREN)
/USB & UART Interface/FTDI_RST: R21.2, U4.14 (~RESET)
/USB & UART Interface/FTDI_VPHY: C8.2, C9.2, FB4.2, U4.4 (VPHY)
/USB & UART Interface/FTDI_VPLL: C5.2, C6.2, FB3.2, U4.9 (VPLL)
/USB & UART Interface/RXA: D2.2 (A), R10.2
/USB & UART Interface/RXB: D4.2 (A), R12.2
/USB & UART Interface/RXC: D6.2 (A), R14.2
/USB & UART Interface/RXD: D8.2 (A), R16.2
/USB & UART Interface/TXA: D1.2 (A), R9.2
/USB & UART Interface/TXB: D3.2 (A), R11.2
/USB & UART Interface/TXC: D5.2 (A), R13.2
/USB & UART Interface/TXD: D7.2 (A), R15.2
/USB & UART Interface/USB_D+: J1.A6 (D+), J1.B6 (D+), U4.8 (DP)
/USB & UART Interface/USB_D-: J1.A7 (D-), J1.B7 (D-), U4.7 (DM)
GND: C3.2, C4.1, C5.1, C6.1, C7.1, C8.1, C9.1, C10.1, C11.1, C12.1, C13.1, C14.1, C15.1, C16.1, C17.1, C18.1, C19.1, D1.1 (K), D2.1 (K), D3.1 (K), D4.1 (K), D5.1 (K), D6.1 (K), D7.1 (K), D8.1 (K), J1.A1 (GND), J1.A12 (GND), J1.B1 (GND), J1.B12 (GND), J1.S1 (SHIELD), R7.2, R8.2, R22.1, U2.8 (GND), U3.5 (GND), U4.1 (GND), U4.5 (GND), U4.10 (AGND), U4.11 (GND), U4.13 (TEST), U4.15 (GND), U4.25 (GND), U4.35 (GND), U4.47 (GND), U4.51 (GND), Y1.2, Y1.4; also elsewhere on the board
unnamed: FB2.2, J1.A4 (VBUS), J1.A9 (VBUS), J1.B4 (VBUS), J1.B9 (VBUS)
unnamed: J1.A5 (CC1), R7.1
unnamed: J1.B5 (CC2), R8.1
unnamed: R9.1, U2.15 (QA)
unnamed: R10.1, U2.1 (QB)
unnamed: R11.1, U2.2 (QC)
unnamed: R12.1, U2.3 (QD)
unnamed: R13.1, U2.4 (QE)
unnamed: R14.1, U2.5 (QF)
unnamed: R15.1, U2.6 (QG)
unnamed: R16.1, U2.7 (QH)
unnamed: R18.2, R19.1, U3.4 (DO)
unnamed: C10.2, U4.2 (OSCI), Y1.3
unnamed: C13.2, U4.3 (OSCO), Y1.1
unnamed: R22.2, U4.6 (REF)

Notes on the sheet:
Colours reversed to match AMBE perspective.
UART ACT LEDs
TRX LEDs for FT4232H See Datasheet Fig 6.6
1.8V VCORE
3.3V VCCIO Decoup.
Don't share board 1V8 as AMBE sequencing is wrong for the FT4232H part.

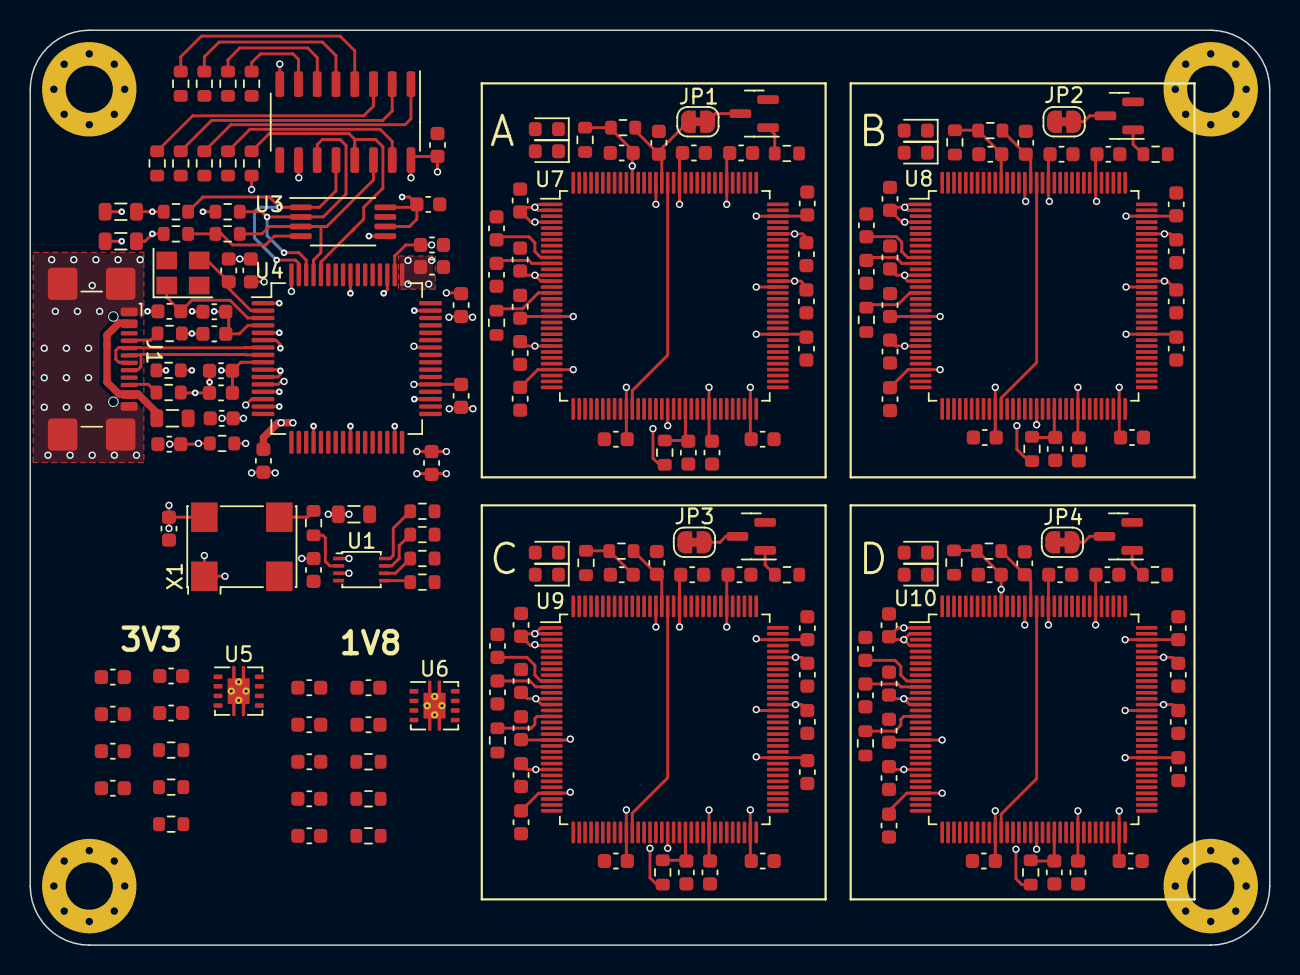
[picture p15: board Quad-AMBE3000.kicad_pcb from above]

Board: 4 copper layers, 84.0 x 62.0 mm, 193 parts (0 on the bottom side), 94 nets.

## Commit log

2024-02-20 Initial files for Quad AMBE-3000R PCB
    [Quad-AMBE3000.kicad_pcb, Quad-AMBE3000.kicad_sch]
2024-02-21 UARTS & PSU finished. Just AMBE-3000R stuff to go
    [Quad-AMBE3000.kicad_sch, psu.kicad_sch, uarts.kicad_sch]
2024-02-23 Added the AMBE-3000F
    [Quad-AMBE3000.kicad_sch, ambe-vocoder.kicad_sch, psu.kicad_sch]
2024-02-23 Schematic V1 done
    [Quad-AMBE3000.kicad_pcb, Quad-AMBE3000.kicad_sch, ambe-vocoder.kicad_sch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]
2024-02-25 Most of the layout done
    [Quad-AMBE3000.kicad_pcb, Quad-AMBE3000.kicad_sch, ambe-vocoder.kicad_sch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]
2024-02-26 Routing finished. Need to tidy DRC & BoM
    [Quad-AMBE3000.kicad_sch]
2024-02-26 Finished DRC review. Warnings for silkscreen overlap with artwork on back side.
2024-02-26 Final updates before manufacture of V1.00
    [Quad-AMBE3000.kicad_sch, ambe-vocoder.kicad_sch, psu.kicad_sch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]
2024-02-27 Fixed USB C BoM option.
    [uarts.kicad_sch]
2024-03-07 Changed Y1 part information from 24MHz to 12MHz
    [Quad-AMBE3000.kicad_sch, ambe-vocoder.kicad_sch, psu.kicad_sch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]
2024-03-11 Added some images of the final board.
